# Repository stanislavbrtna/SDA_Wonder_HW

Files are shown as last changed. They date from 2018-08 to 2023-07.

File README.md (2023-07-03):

# SDA Mk. 2 Hardware Sources
In the Board directory are KiCad project files for the Boards used in the SDA and in the case Directory there are FreeCAD files for the SDA case. You can find more info about the SDA Project on its [project page](https://hackaday.io/project/35165-sda-the-best-new-pda) on hackaday.io.

## Known Bugs - Rev2b (current)

 1. SD card slot casing is not grounded on the pcb, sd card insertion detection doesn't work because of it. This can be fixed by scraping off the protective mask near the pin and bridging ground and shielding  with a bit of solder.
 2. Pads for battery connector are too small and can be ripped out of place when device falls form sufficient height. This is sort-of fixed with second revision of the case by giving the battery better support.
 3. The stacked PCBs are a point of failure, stress is built up in the connecting pins during soldering. This stress can break the contacts after few years of use, temperature changes, drops of the device. Luckily, re-soldering these pins is an easy job.

## Known Bugs - Rev1

 1. Vcc is used as Vref, if battery goes under 3.3V, then ADC measurements are wrong.
 2. There is no under-voltage protection at the moment.
 3. There is currently no guide for battery connector alignment, if battery connector is misaligned battery doesn't make good contact. 

## Case R2 notes
Second revision was printed and tested. It contains optional holes for a speaker and a microphone. The add-on module and cradle works well. 

## Case notes
 Only the 3D printable case for SDA was printed and tested, the FreeCAD file also contains drawings of a cradle and an add-on module, those are still work-in progress.

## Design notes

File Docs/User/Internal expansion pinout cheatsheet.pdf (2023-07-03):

+ AFs | MCU pin | Exc pin number | Connector number | Connector number | Exc pin number | MCU pin | + AFs
TIM4_CH4 | PD15 | 01 | 1 | 2 | 09 | PB15 | SPI2_MOSI
TIM4_CH3 | PD14 | 02 | 3 | 4 | 10 | PB14 | SPI2_MISO
TIM4_CH2, TIM12_CH2 | PD13 | 03 | 5 | 6 | 11 | PB13 | SPI2_SCK
TIM4_CH1 | PD12 | 04 | 7 | 8 | GND | - | -
- | PD11 | 05 | 9 | 10 | VCC 3.3V | - | -
- | PD10 | 06 | 11 | 12 | 14 | PE12 | -
USART3_RX | PD09 | 07 | 13 | 14 | 15 | PE13 | TIM1_CH3
USART3_TX | PD08 | 08 | 15 | 16 | 16 | PE14 | TIM1_CH4

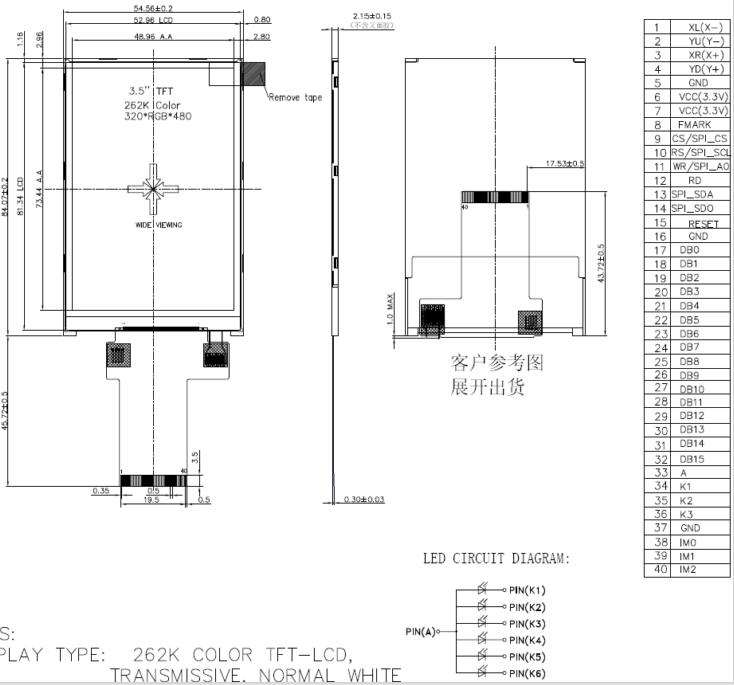
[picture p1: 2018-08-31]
Docs/Datasheets/LCD/lcd_pinout.jpg

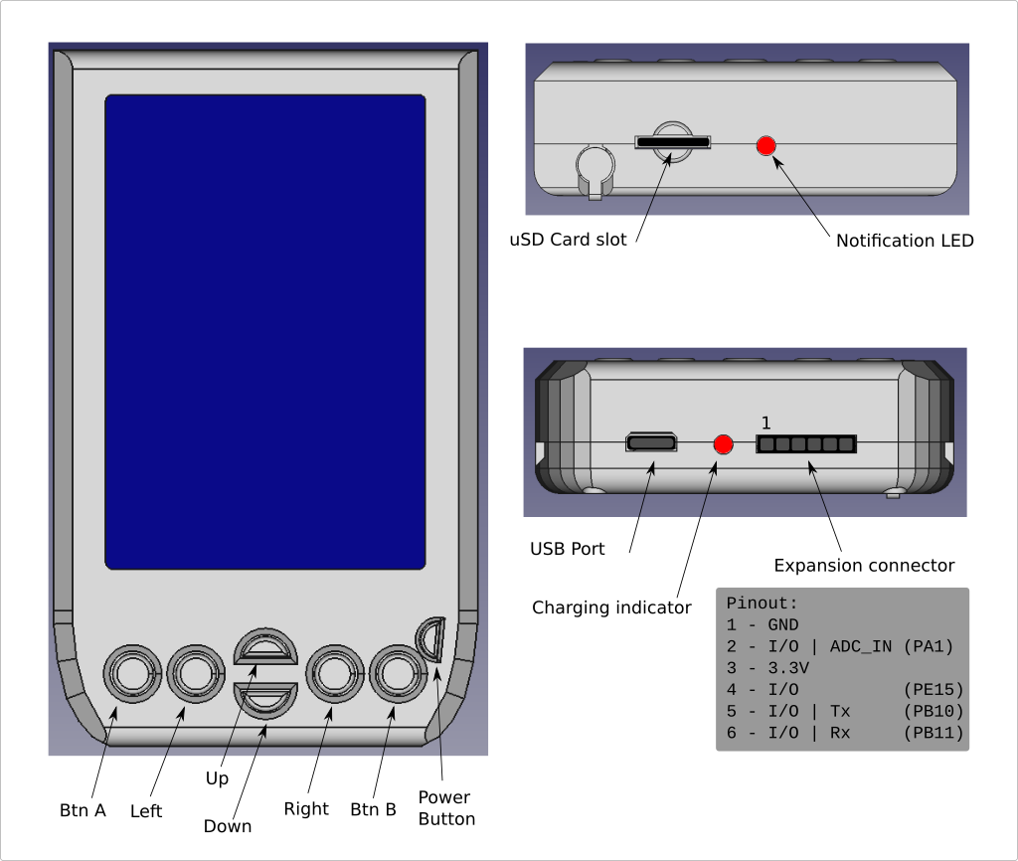
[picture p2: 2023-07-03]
Docs/User/diagram.png

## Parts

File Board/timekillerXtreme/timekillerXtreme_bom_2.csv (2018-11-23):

Component | Description | Part | References | Value | Footprint | Quantity Per PCB | Datasheet | TME_Part_number
1 | Unpolarized capacitor | C | C5 C7 C8 C13 C15 C16 C19 C20 C23 C28 C31 C32 | 100n | C_0805_HandSoldering | 12
2 | Unpolarized capacitor | C | C24 | 100u | C_1210_HandSoldering | 1
3 | Unpolarized capacitor | C | C14 C21 C22 C29 C33 | 2.2u | C_0805_HandSoldering | 5
4 | Unpolarized capacitor | C | C9 C10 | 3.3p | C_0805_HandSoldering | 2
5 | Unpolarized capacitor | C | C3 C4 C18 C30 | 4.7u | C_0805_HandSoldering | 4
6 | Unpolarized capacitor | C | C1 C2 | 47p | C_0805_HandSoldering | 2
7 | Unpolarized capacitor | C | C6 C17 | 47u | C_1210_HandSoldering | 2
8 | Unpolarized capacitor | C | C11 C12 | 8.2p | C_0805_HandSoldering | 2
9 | Diode | D | D2 | 1N4148 | D_MiniMELF | 1
10 | LED generic | LED | D1 | CHRG_LED | LED_D3.0mm_FlatTop | 1
11 | LED generic | LED | D4 | SYS_LED | LED_D3.0mm_FlatTop | 1
12 | Fuse, generic | Fuse | F1 | 1A | R_0805_HandSoldering | 1
13 | Generic connector, single row, 01x03 | Conn_01x03 | J1 | Battery | Conn_Nokia_BL-5C | 1
14 | point | TEST_1P | J7 | CAPTEST | Measurement_Point_Round-SMD-Pad_Small | 1
15 | Generic connector, single row, 01x03 | Conn_01x03 | J13 | CONN_01X03 | Pin_Header_Straight_1x03_Pitch1.27mm | 1
16 | Generic connector, single row, 01x02 | Conn_01x02 | J10 | Conn_01x02 | Pin_Header_Straight_1x02_Pitch2.00mm | 1
17 | Generic connector, single row, 01x06 | Conn_01x06 | J3 | Conn_Bottom_Expansion | Pin_Header__1x06_Pitch2.54mm-NoSilk | 1
18 | Generic connector, double row, 02x08, counter clockwise pin numbering scheme (similar to DIP packge numbering) | Conn_02x08_Counter_Clockwise | J4 | Conn_Internal_Expansion | Pin_Header_Straight_2x08_Pitch1.27mm | 1
19 | Generic connector, double row, 02x10, top/bottom pin numbering scheme (row 1: 1...pins_per_row, row2: pins_per_row+1 ... num_pins) | Conn_02x10_Top_Bottom | J5 | Conn_LCD_Board | Pin_Header_Straight_2x10_Pitch2.00mm | 1
20 | point | TEST_1P | J21 | PD0 | Measurement_Point_Round-SMD-Pad_Small | 1
21 | point | TEST_1P | J20 | PD1 | Measurement_Point_Round-SMD-Pad_Small | 1
22 | point | TEST_1P | J22 | PD3 | Measurement_Point_Round-SMD-Pad_Small | 1
23 | point | TEST_1P | J19 | PD4 | Measurement_Point_Round-SMD-Pad_Small | 1
24 | point | TEST_1P | J18 | PE10 | Measurement_Point_Round-SMD-Pad_Small | 1
25 | point | TEST_1P | J23 | PE11 | Measurement_Point_Round-SMD-Pad_Small | 1
26 | point | TEST_1P | J16 | PE8 | Measurement_Point_Round-SMD-Pad_Small | 1
27 | point | TEST_1P | J17 | PE9 | Measurement_Point_Round-SMD-Pad_Small | 1
28 | Generic connector, single row, 01x06 | Conn_01x06 | J12 | PROG | Pin_Header_Straight_1x06_Pitch1.27mm | 1
29 | point | TEST_1P | J24 | Pb12 | Measurement_Point_Round-SMD-Pad_Small | 1
30 | point | TEST_1P | J14 | TP_3.3V | Measurement_Point_Round-SMD-Pad_Small | 1
31 | point | TEST_1P | J9 | TP_AUDIO_L | Measurement_Point_Round-SMD-Pad_Small | 1
32 | point | TEST_1P | J8 | TP_AUDIO_R | Measurement_Point_Round-SMD-Pad_Small | 1
33 | point | TEST_1P | J25 | TP_BATT | Measurement_Point_Round-SMD-Pad_Small | 1
34 | point | TEST_1P | J11 | TP_USB | Measurement_Point_Round-SMD-Pad_Small | 1
35 | USB mini/micro connector | USB_OTG | J2 | USB_OTG | USB_Micro-B-CircularHoles | 1
36 |  | uSD-RESCUE-timekillerXtreme | J6 | uSD | ATTEND-SD-TME | 1 |  | ATTEND 112J-TDAR-R01
37 | Inductor | L | L1 | 4.7uH | L4x4mm | 1
38 | -60V Vds, -0.18A Id, P-Channel MOSFET, SOT-23-3 | NTR2101P | Q1 | IRLML6302 | SOT-23_Handsoldering | 1 | http://www.vishay.com/docs/70209/70209.pdf
39 | Transistor NPN (general) | Q_NPN_BCE | Q2 | PMBT3904.215 | SOT-23_Handsoldering | 1
40 | Resistor | R | R10 R11 R17 R18 | 0 | R_0603 | 4
41 | Resistor | R | R19 | 0 | R_0805_HandSoldering | 1
42 | Resistor | R | R1 R12 R13 R24 | 10k | R_0805_HandSoldering | 4
43 | Resistor | R | R9 | 150K | R_0805_HandSoldering | 1
44 | Resistor | R | R2 R14 R15 | 15k | R_0805_HandSoldering | 3
45 | Resistor | R | R16 | 220 | R_0805_HandSoldering | 1
46 | Resistor | R | R3 R4 | 27R | R_0805_HandSoldering | 2
47 | Resistor | R | R5 | 2k | R_0805_HandSoldering | 1
48 | Resistor | R | R6 | 470R | R_0805_HandSoldering | 1
49 | Resistor | R | R7 R20 R21 R22 R23 | 47k | R_0805_HandSoldering | 5
50 | Resistor | R | R8 | 680K | R_0805_HandSoldering | 1
51 | Single Pole Single Throw (SPST) switch | SW_SPST | SW2 | A | SW_PUSH_6mm_h5mm | 1
52 | Single Pole Single Throw (SPST) switch | SW_SPST | SW3 | B | SW_PUSH_6mm_h5mm | 1
53 | Single Pole Single Throw (SPST) switch | SW_SPST | SW6 | DOWN | SW_PUSH_6mm_h5mm | 1
54 | Single Pole Single Throw (SPST) switch | SW_SPST | SW4 | LEFT | SW_PUSH_6mm_h5mm | 1
55 | Single Pole Single Throw (SPST) switch | SW_SPST | SW1 | PWR | SW_PUSH_6mm_h5mm | 1
56 | Single Pole Single Throw (SPST) switch | SW_SPST | SW5 | RIGHT | SW_PUSH_6mm_h5mm | 1
57 | Single Pole Single Throw (SPST) switch | SW_SPST | SW8 | RST | SW_PUSH_6mm_h4.3mm | 1
58 | Single Pole Single Throw (SPST) switch | SW_SPST | SW7 | UP | SW_PUSH_6mm_h5mm | 1
59 | Cmos switch, SOT23-5 | AOZ1310 | U7 | AOZ1310 | SOT-23-5_HandSoldering | 1
60 |  | FT230XS-R | U2 | FT230XS-R | SSOP-16_5.3x6.2mm_Pitch0.65mm | 1
61 |  | MCP73831 | U1 | MCP73831 | SOT-23-5_HandSoldering | 1
62 |  | NCP1529 | U3 | NCP1529 | SOT-23-5_HandSoldering | 1
63 |  | STM32F407VGT6 | U5 | STM32F407VGT6 | LQFP-100_14x14mm_Pitch0.5mm | 1
64 |  | TLV431 | U4 | TLV431 | TSOT-23 | 1
65 |  | USBLC6 | U6 U8 U9 | USBLC6 | SOT-23-6_Handsoldering | 3
66 | point | TEST_1P | VREF1 | VREF | Measurement_Point_Round-SMD-Pad_Small | 1
67 | Two pin crystal | Crystal | Y2 | 16MHz | Crystal_SMD_HC49-HS-mini | 1
68 | Two pin crystal | Crystal | Y1 | 32.768 KHz | xtall_epso_mc146 | 1
Component Groups: | 68
Component Count: | 105
Fitted Components: | 105
Number of PCBs: | 1
Total components: | 105
Schematic Version: | 2
Schematic Date: | 2018-11-15
BoM Date: | P23.listopad2018,12:11:02CET
Schematic Source: | /home/stanislaw/SDA/2.0 Wonder/Board/timekillerXtreme/timekillerXtreme.sch
KiCad Version: | Eeschema 4.0.7-e2-6376~58~ubuntu16.04.1

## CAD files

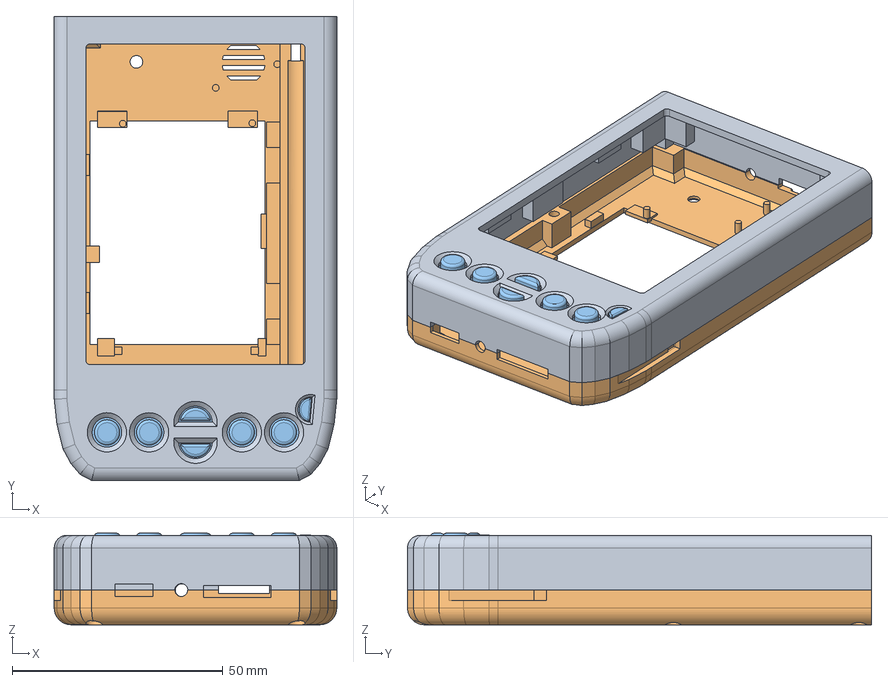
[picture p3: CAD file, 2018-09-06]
Case/wonder.fcstd
67.0 x 110.0 x 21.7 mm
Back
Buttons

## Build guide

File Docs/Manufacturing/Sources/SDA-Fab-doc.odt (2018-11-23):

Description | Part | References | Value | Quantity Per PCB
Unpolarized capacitor | C | C5 C7 C8 C13 C15 C16 C19 C20 C23 C28 C31 C32 | 100n | 12
Unpolarized capacitor | C | C24 | 100u | 1
Unpolarized capacitor | C | C14 C21 C22 C29 C33 | 2.2u | 5
Unpolarized capacitor | C | C9 C10 | 3.3p | 2
Unpolarized capacitor | C | C3 C4 C18 C30 | 4.7u | 4
Unpolarized capacitor | C | C1 C2 | 47p | 2
Unpolarized capacitor | C | C6 C17 | 47u | 2
Unpolarized capacitor | C | C11 C12 | 8.2p | 2
Diode | D | D2 | 1N4148 | 1
LED generic | LED | D1 | CHRG_LED | 1
LED generic | LED | D4 | SYS_LED | 1
Fuse, generic | Fuse | F1 | 1A | 1
Conn_Nokia_BL-5C | Conn_01x03 | J1 | Battery Connector | 1
Generic connector, 01x03 | Conn_01x03 | J13 | CONN_01X03 | 1
External expansion connector | Conn_01x06 | J3 | Conn_Bottom_Expansion | 1
Internal expansion connector | Conn_02x08 | J4 | Conn_Internal_Expansion | 1
Programming connector | Conn_01x06 | J12 | PROG | 1
SD card slot | uSD-timekillerXtreme | J6 | uSD | 1
Inductor | L | L1 | 4.7uH | 1
P-Channel MOSFET, SOT-23-3 | NTR2101P | Q1 | IRLML6302 | 1
Transistor NPN (general) | Q_NPN_BCE | Q2 | PMBT3904.215 | 1
Resistor | R | R19 | 0 | 1
Resistor | R | R1 R12 R13 R24 | 10k | 4
Resistor | R | R9 | 150k | 1
Resistor | R | R2 R14 R15 | 15k | 3
Resistor | R | R16 | 220 | 1
Resistor | R | R3 R4 | 27R | 2
Resistor | R | R5 | 2k | 1
Resistor | R | R6 | 470R | 1
Resistor | R | R7 R20 R21 R22 R23 | 47k | 5
Resistor | R | R8 | 680k | 1
Single Pole Single Throw (SPST) switch | SW_SPST | SW8 | RST | 1
Single Pole Single Throw (SPST) switch | SW_SPST | SW1 - SW7 | A, B, L, R, U, D, PWR | 7
Cmos switch, SOT23-5 | AOZ1310 | U7 | AOZ1310 | 1
FTDI usb to seriál | FT230XS-R | U2 | FT230XS-R | 1
Battery management | MCP73831 | U1 | MCP73831 | 1
Voltage reg. | NCP1529 | U3 | NCP1529 | 1
MCU | STM32F407VGT6 | U5 | STM32F407VGT6 | 1
Voltage refrerence | TLV431 | U4 | TLV431 | 1
ESD protection | USBLC6 | U6 U8 U9 | USBLC6 | 3
Two pin crystal | Crystal | Y2 | 16MHz | 1

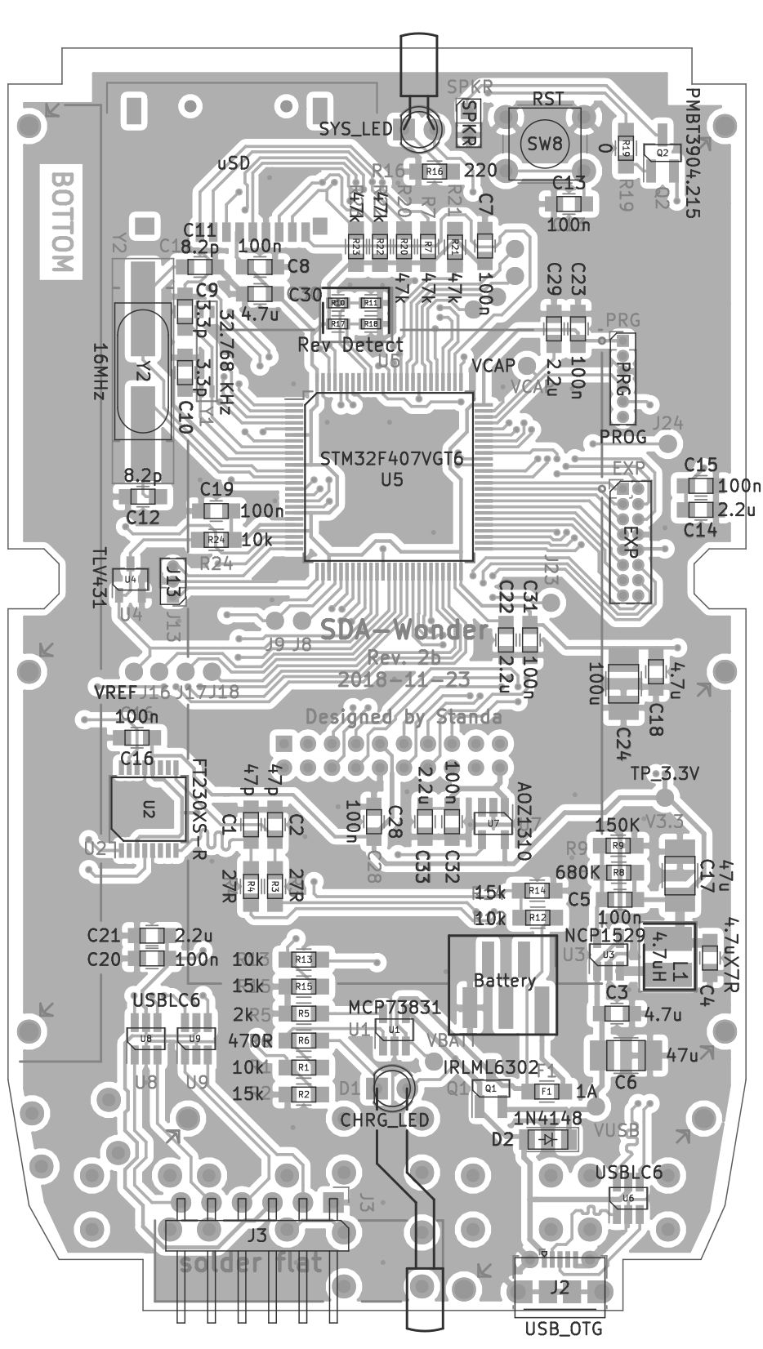
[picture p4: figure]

Two pin crystal SDA-Wonder Rev2b Assembly docs, Standa 2018 hackaday.io/project/35165-sda-the-best-new-pda github.com/stanislavbrtna/SDA_Wonder_HW | Crystal | Y1 | 32.768 KHz | 1

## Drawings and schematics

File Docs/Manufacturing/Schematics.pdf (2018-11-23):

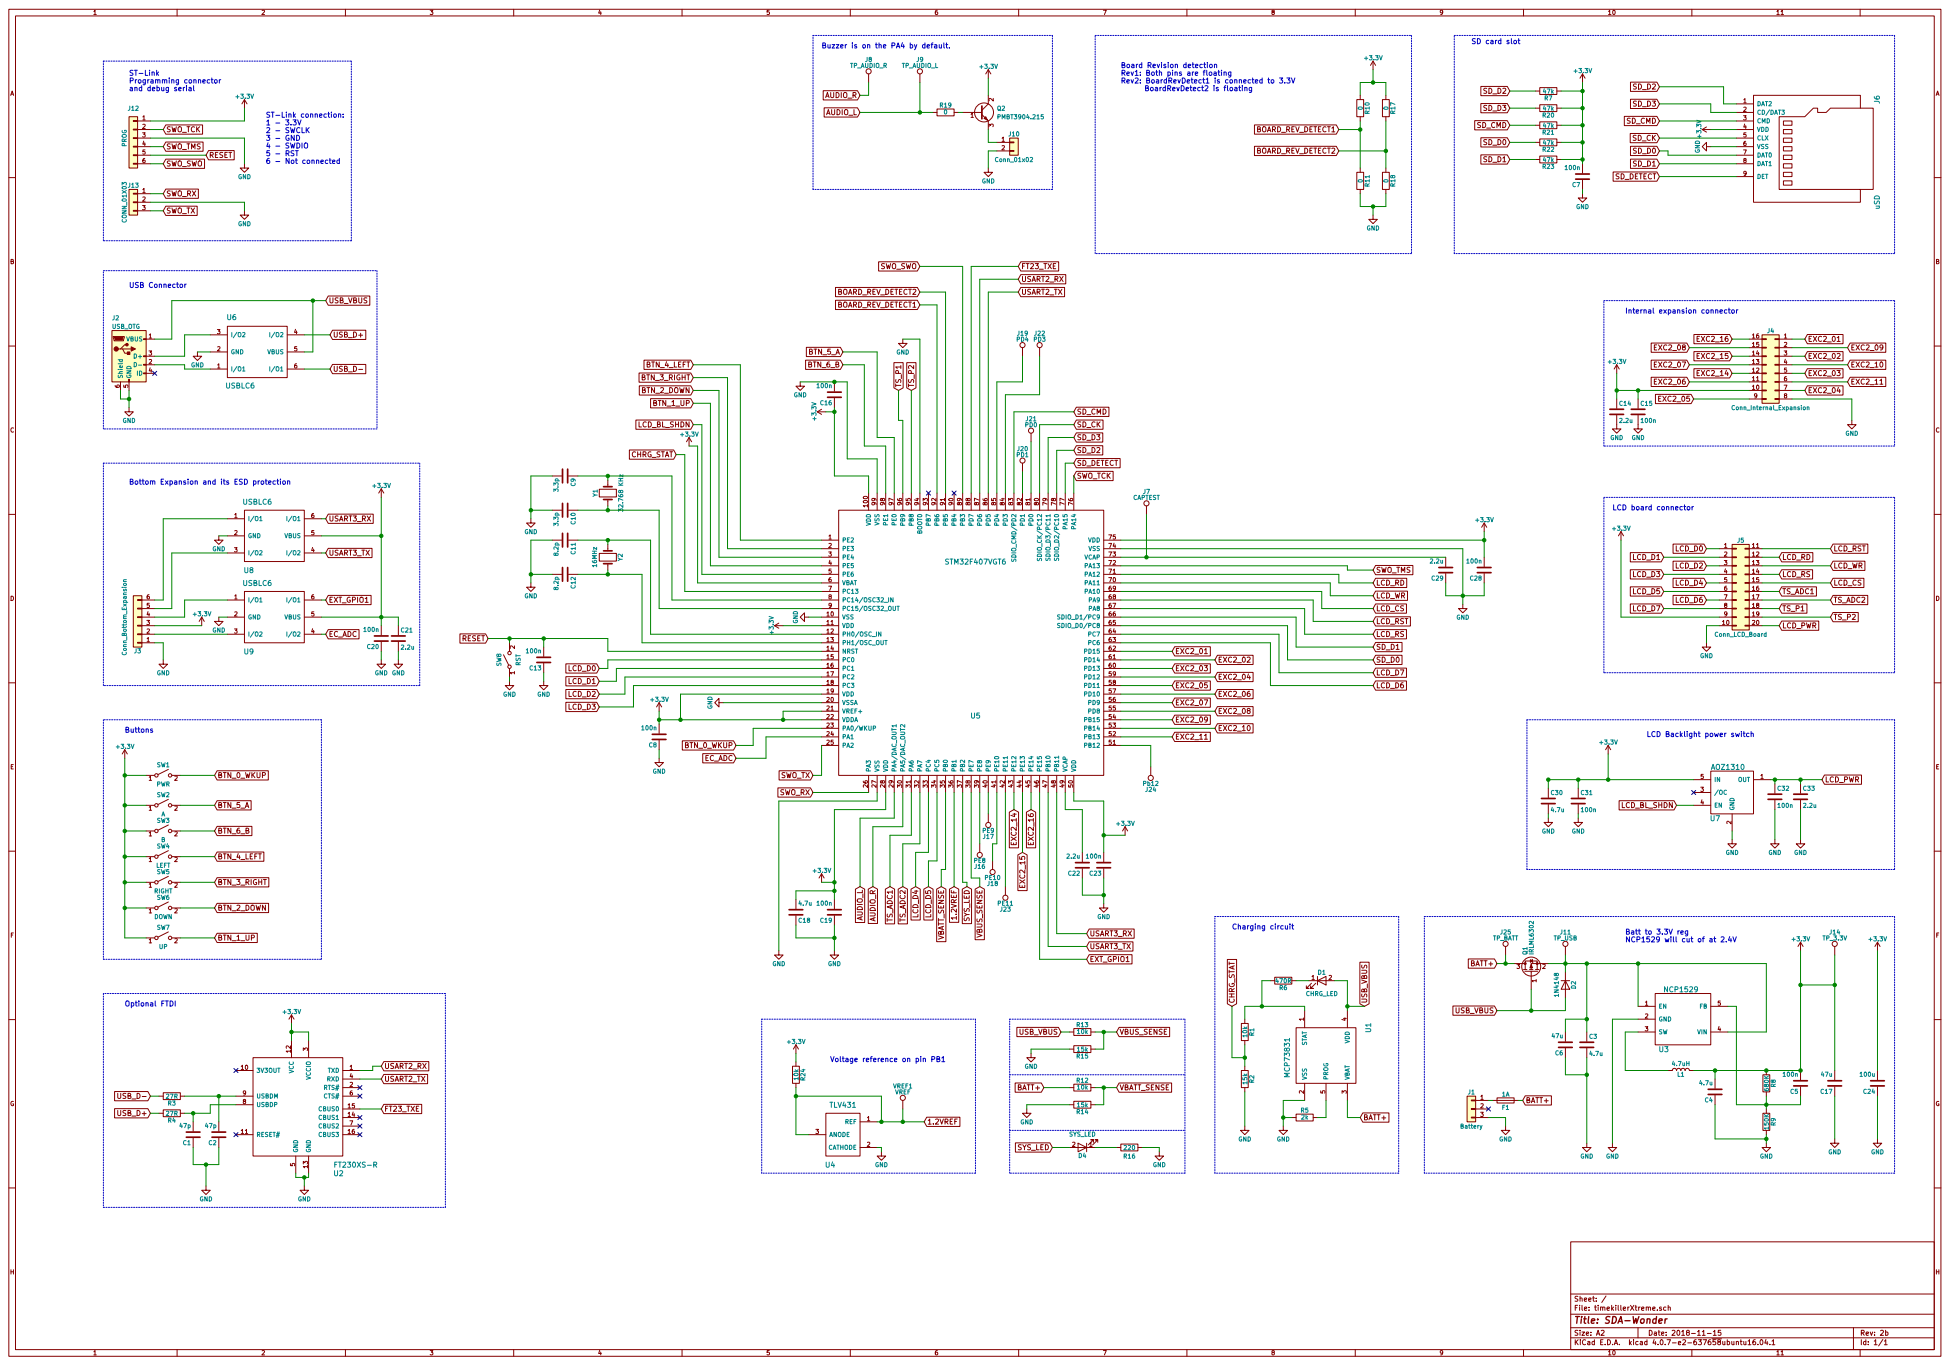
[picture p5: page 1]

Description | Part | References | Value | Quantity Per PCB
Unpolarized capacitor | C | C5 C7 C8 C13 C15 C16 C19 C20 C23 C28 C31 C32 | 100n | 12
Unpolarized capacitor | C | C24 | 100u | 1
Unpolarized capacitor | C | C14 C21 C22 C29 C33 | 2.2u | 5
Unpolarized capacitor | C | C9 C10 | 3.3p | 2
Unpolarized capacitor | C | C3 C4 C18 C30 | 4.7u | 4
Unpolarized capacitor | C | C1 C2 | 47p | 2
Unpolarized capacitor | C | C6 C17 | 47u | 2
Unpolarized capacitor | C | C11 C12 | 8.2p | 2
Diode | D | D2 | 1N4148 | 1
LED generic | LED | D1 | CHRG_LED | 1
LED generic | LED | D4 | SYS_LED | 1
Fuse, generic | Fuse | F1 | 1A | 1
Conn_Nokia_BL-5C | Conn_01x03 | J1 | Battery Connector | 1
Generic connector, 01x03 | Conn_01x03 | J13 | CONN_01X03 | 1
External expansion connector | Conn_01x06 | J3 | Conn_Bottom_Expansion | 1
Internal expansion connector | Conn_02x08 | J4 | Conn_Internal_Expansion | 1
Programming connector | Conn_01x06 | J12 | PROG | 1
SD card slot | uSD-timekillerXtreme | J6 | uSD | 1
Inductor | L | L1 | 4.7uH | 1
P-Channel MOSFET, SOT-23-3 | NTR2101P | Q1 | IRLML6302 | 1
Transistor NPN (general) | Q_NPN_BCE | Q2 | PMBT3904.215 | 1
Resistor | R | R19 | 0 | 1
Resistor | R | R1 R12 R13 R24 | 10k | 4
Resistor | R | R9 | 150k | 1
Resistor | R | R2 R14 R15 | 15k | 3
Resistor | R | R16 | 220 | 1
Resistor | R | R3 R4 | 27R | 2
Resistor | R | R5 | 2k | 1
Resistor | R | R6 | 470R | 1
Resistor | R | R7 R20 R21 R22 R23 | 47k | 5
Resistor | R | R8 | 680k | 1
Single Pole Single Throw (SPST) switch | SW_SPST | SW8 | RST | 1
Single Pole Single Throw (SPST) switch | SW_SPST | SW1 - SW7 | A, B, L, R, U, D, PWR | 7
Cmos switch, SOT23-5 | AOZ1310 | U7 | AOZ1310 | 1
FTDI usb to seriál | FT230XS-R | U2 | FT230XS-R | 1
Battery management | MCP73831 | U1 | MCP73831 | 1
Voltage reg. | NCP1529 | U3 | NCP1529 | 1
MCU | STM32F407VGT6 | U5 | STM32F407VGT6 | 1
Voltage refrerence | TLV431 | U4 | TLV431 | 1
ESD protection | USBLC6 | U6 U8 U9 | USBLC6 | 3
Two pin crystal | Crystal | Y2 | 16MHz | 1
Two pin crystal | Crystal | Y1 | 32.768 KHz | 1

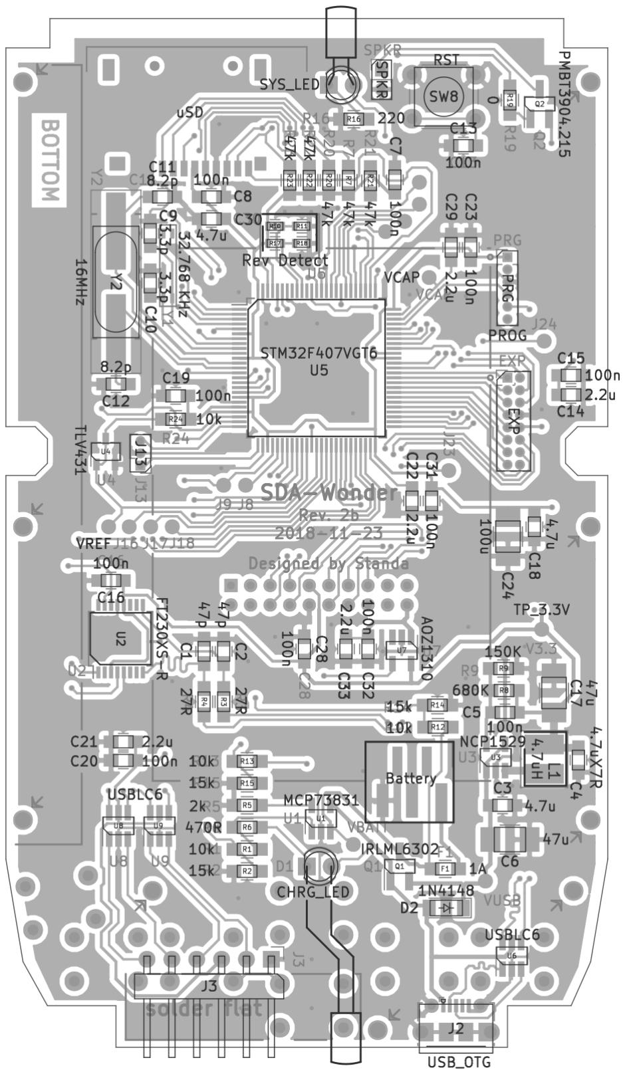
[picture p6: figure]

## SDA-Wonder Rev2b Assembly docs, Standa 2018

### hackaday.io/project/35165-sda-the-best-new-pda github.com/stanislavbrtna/SDA_Wonder_HW

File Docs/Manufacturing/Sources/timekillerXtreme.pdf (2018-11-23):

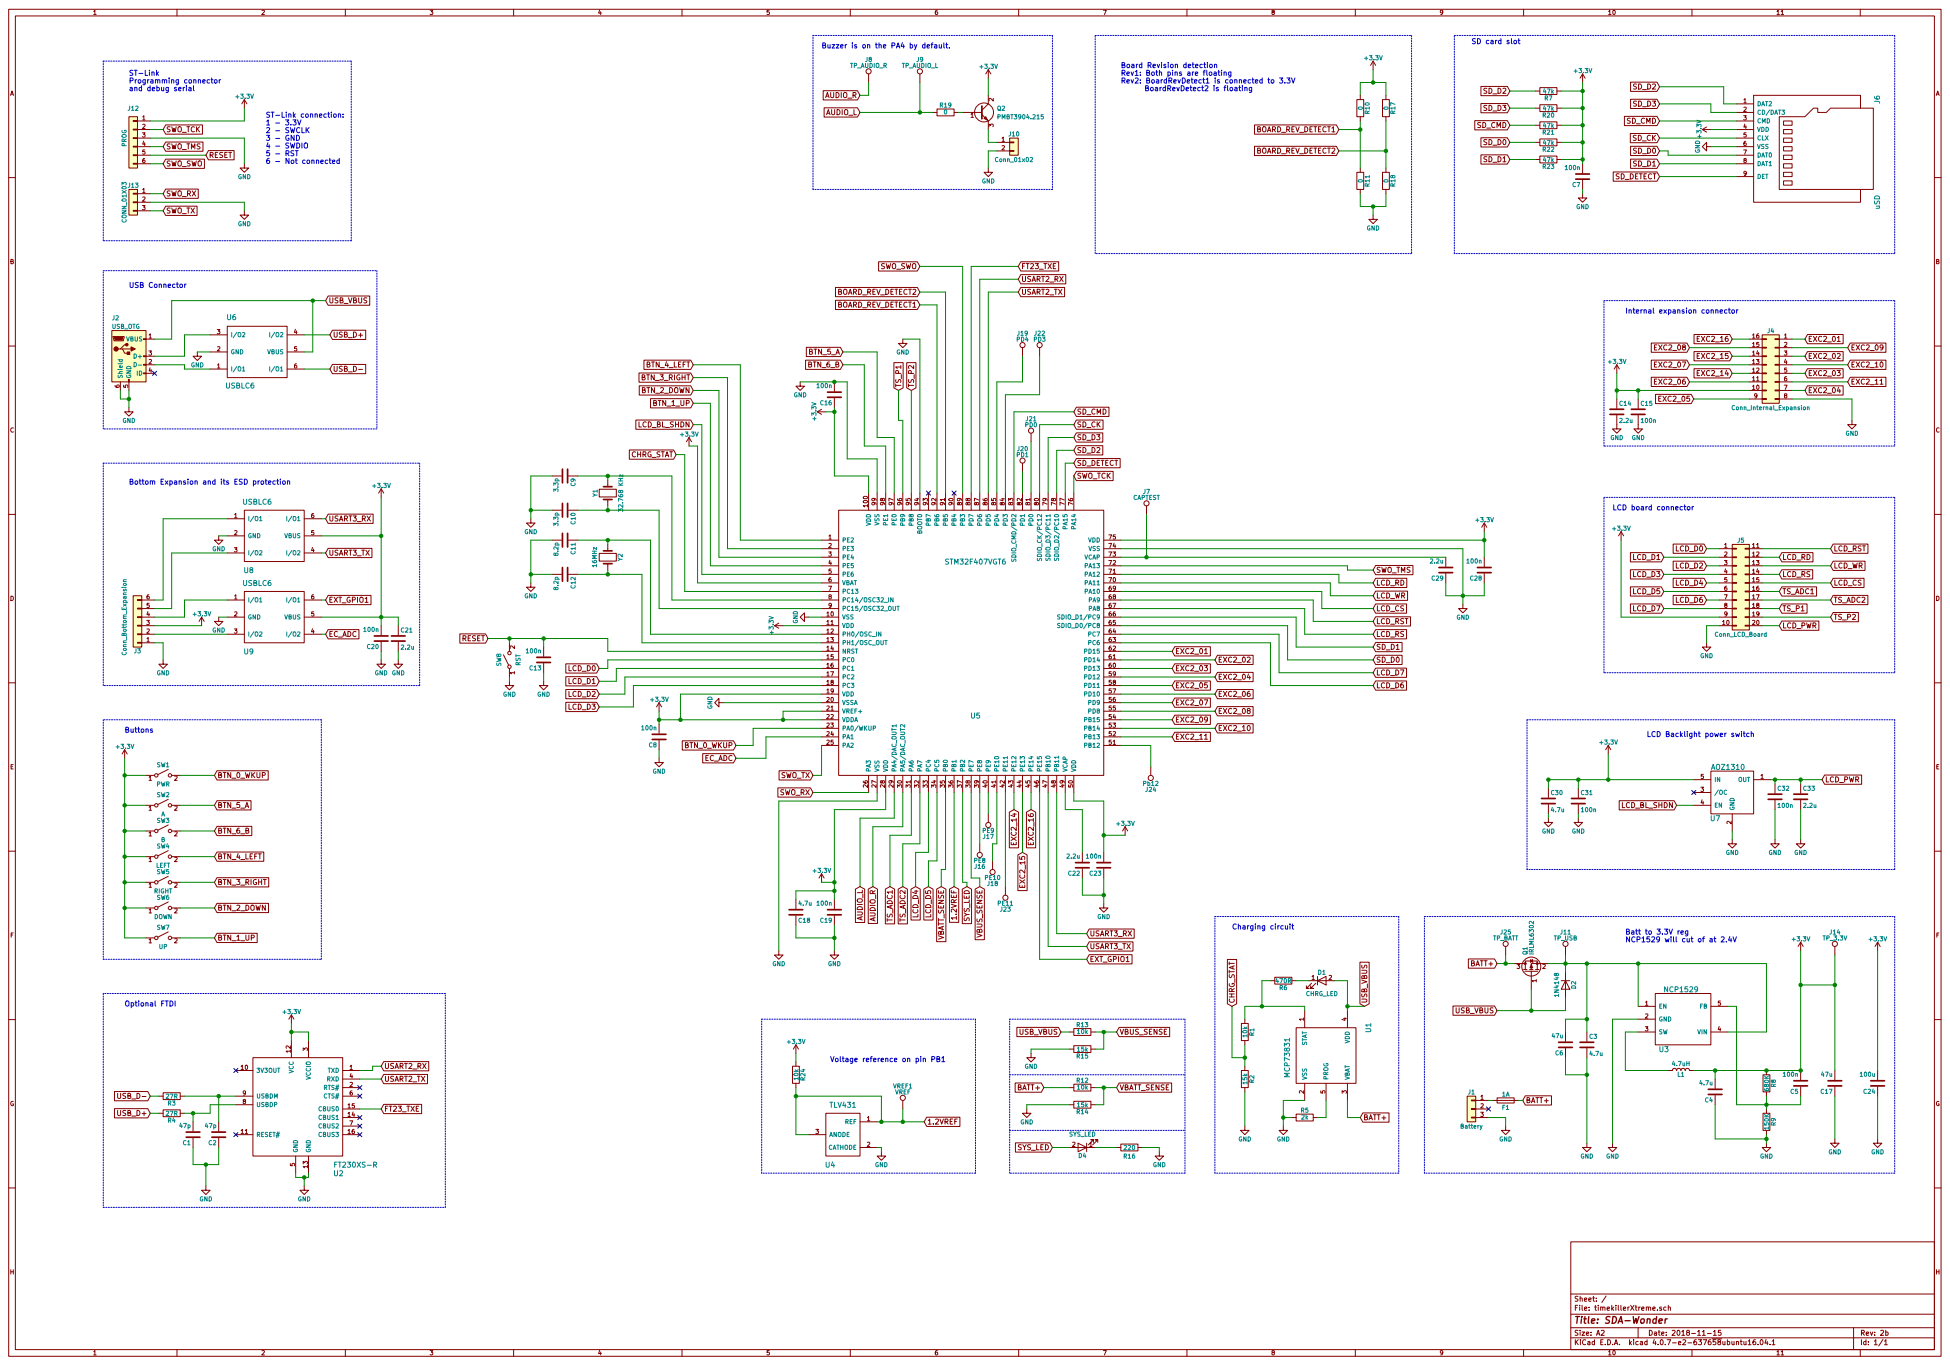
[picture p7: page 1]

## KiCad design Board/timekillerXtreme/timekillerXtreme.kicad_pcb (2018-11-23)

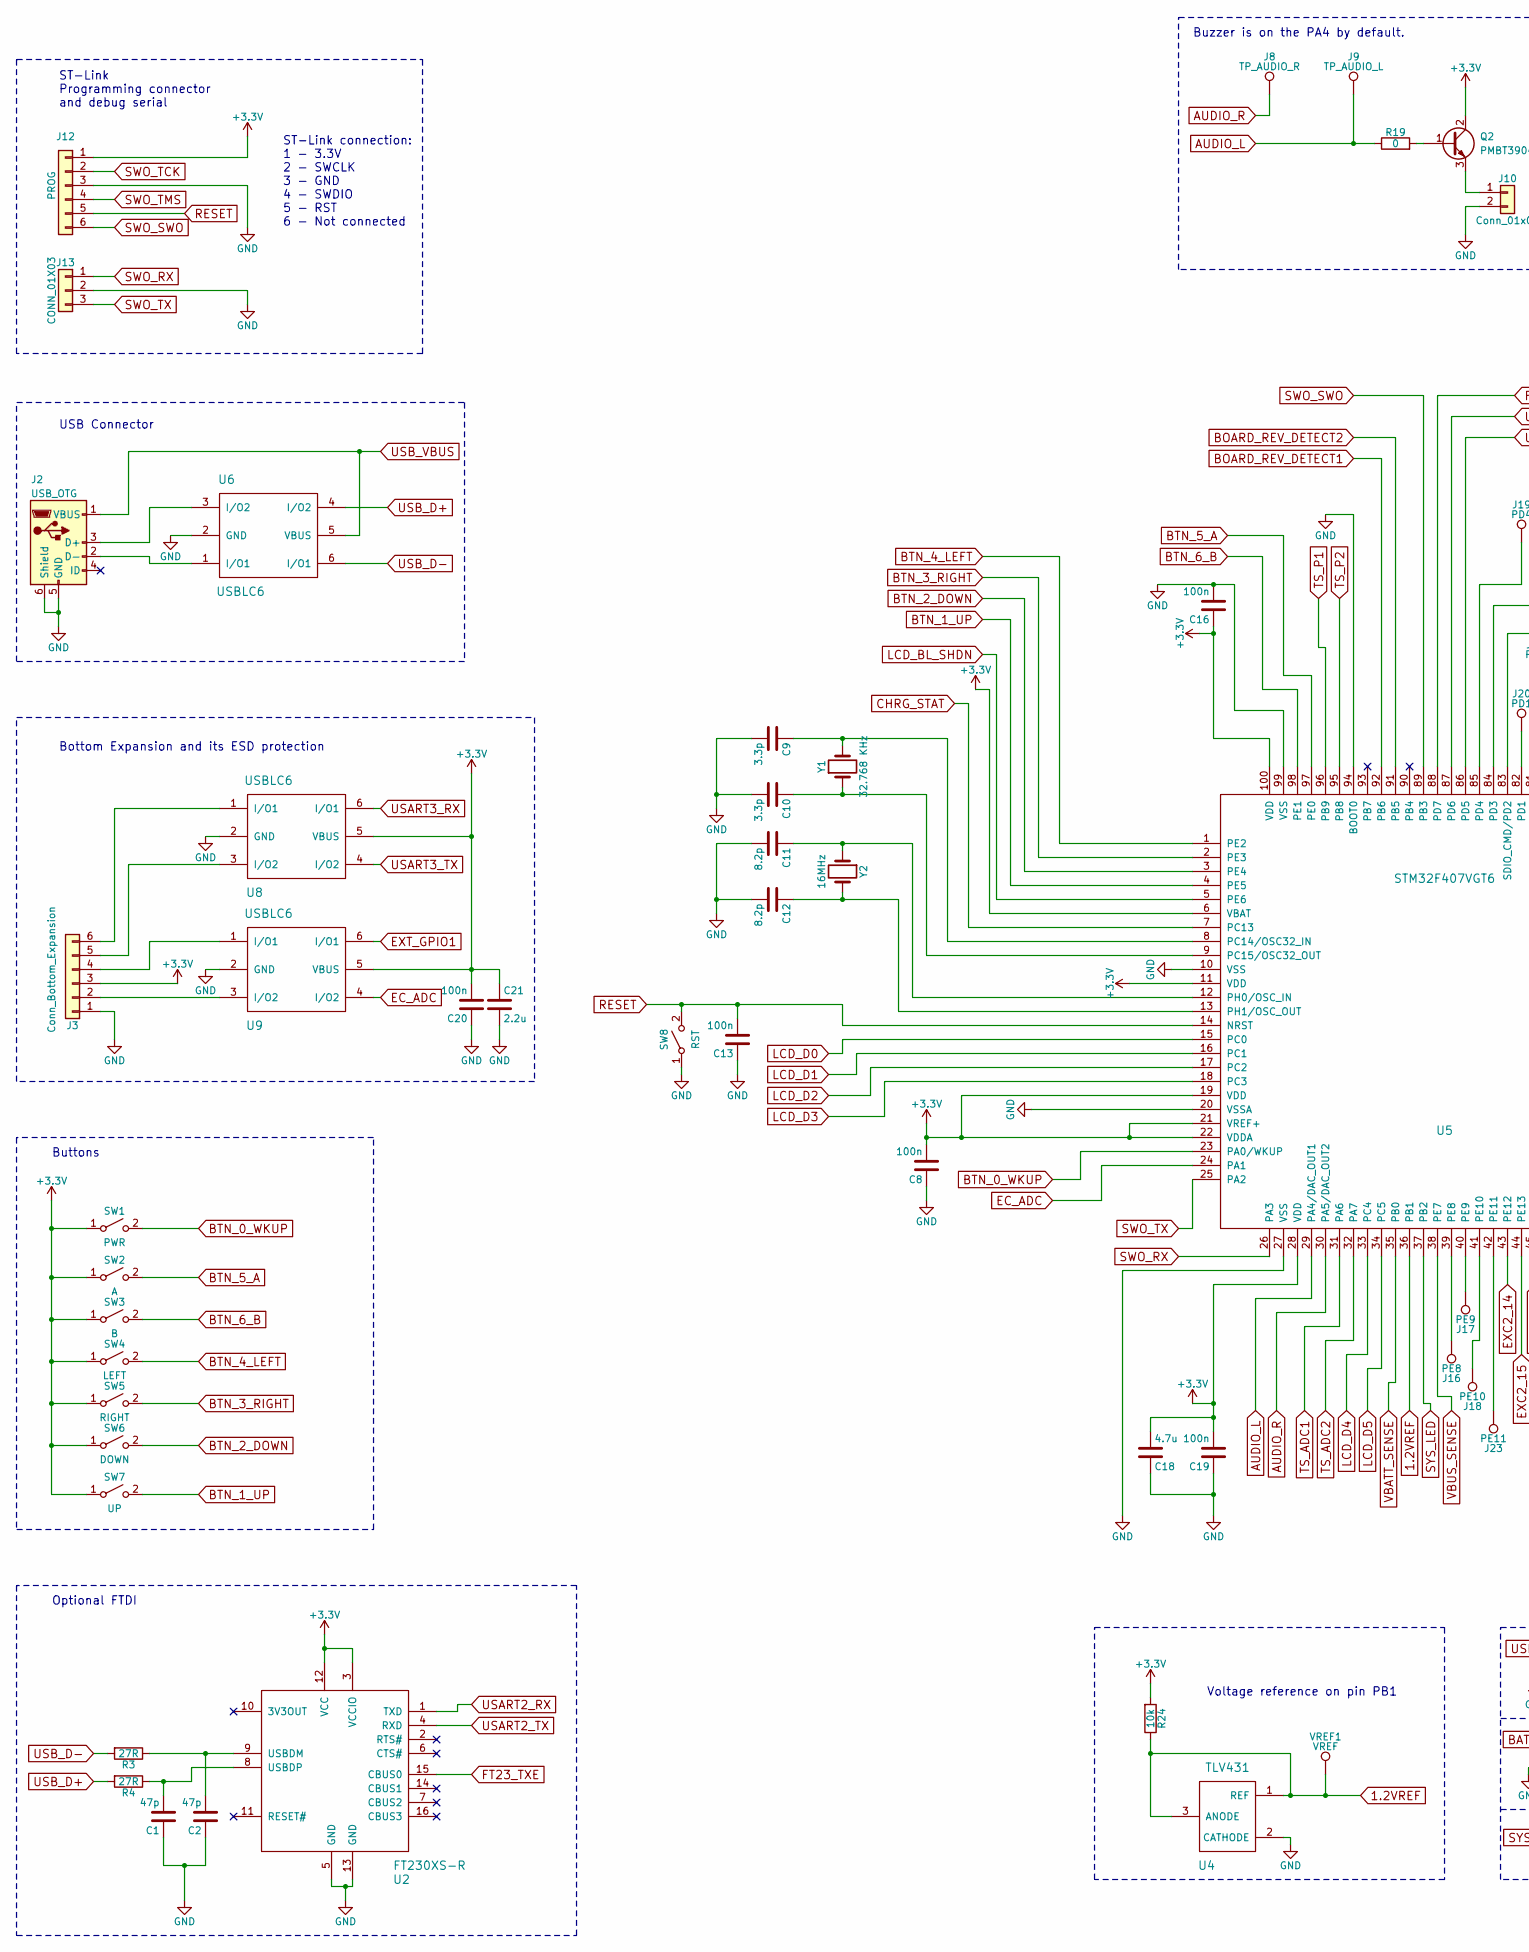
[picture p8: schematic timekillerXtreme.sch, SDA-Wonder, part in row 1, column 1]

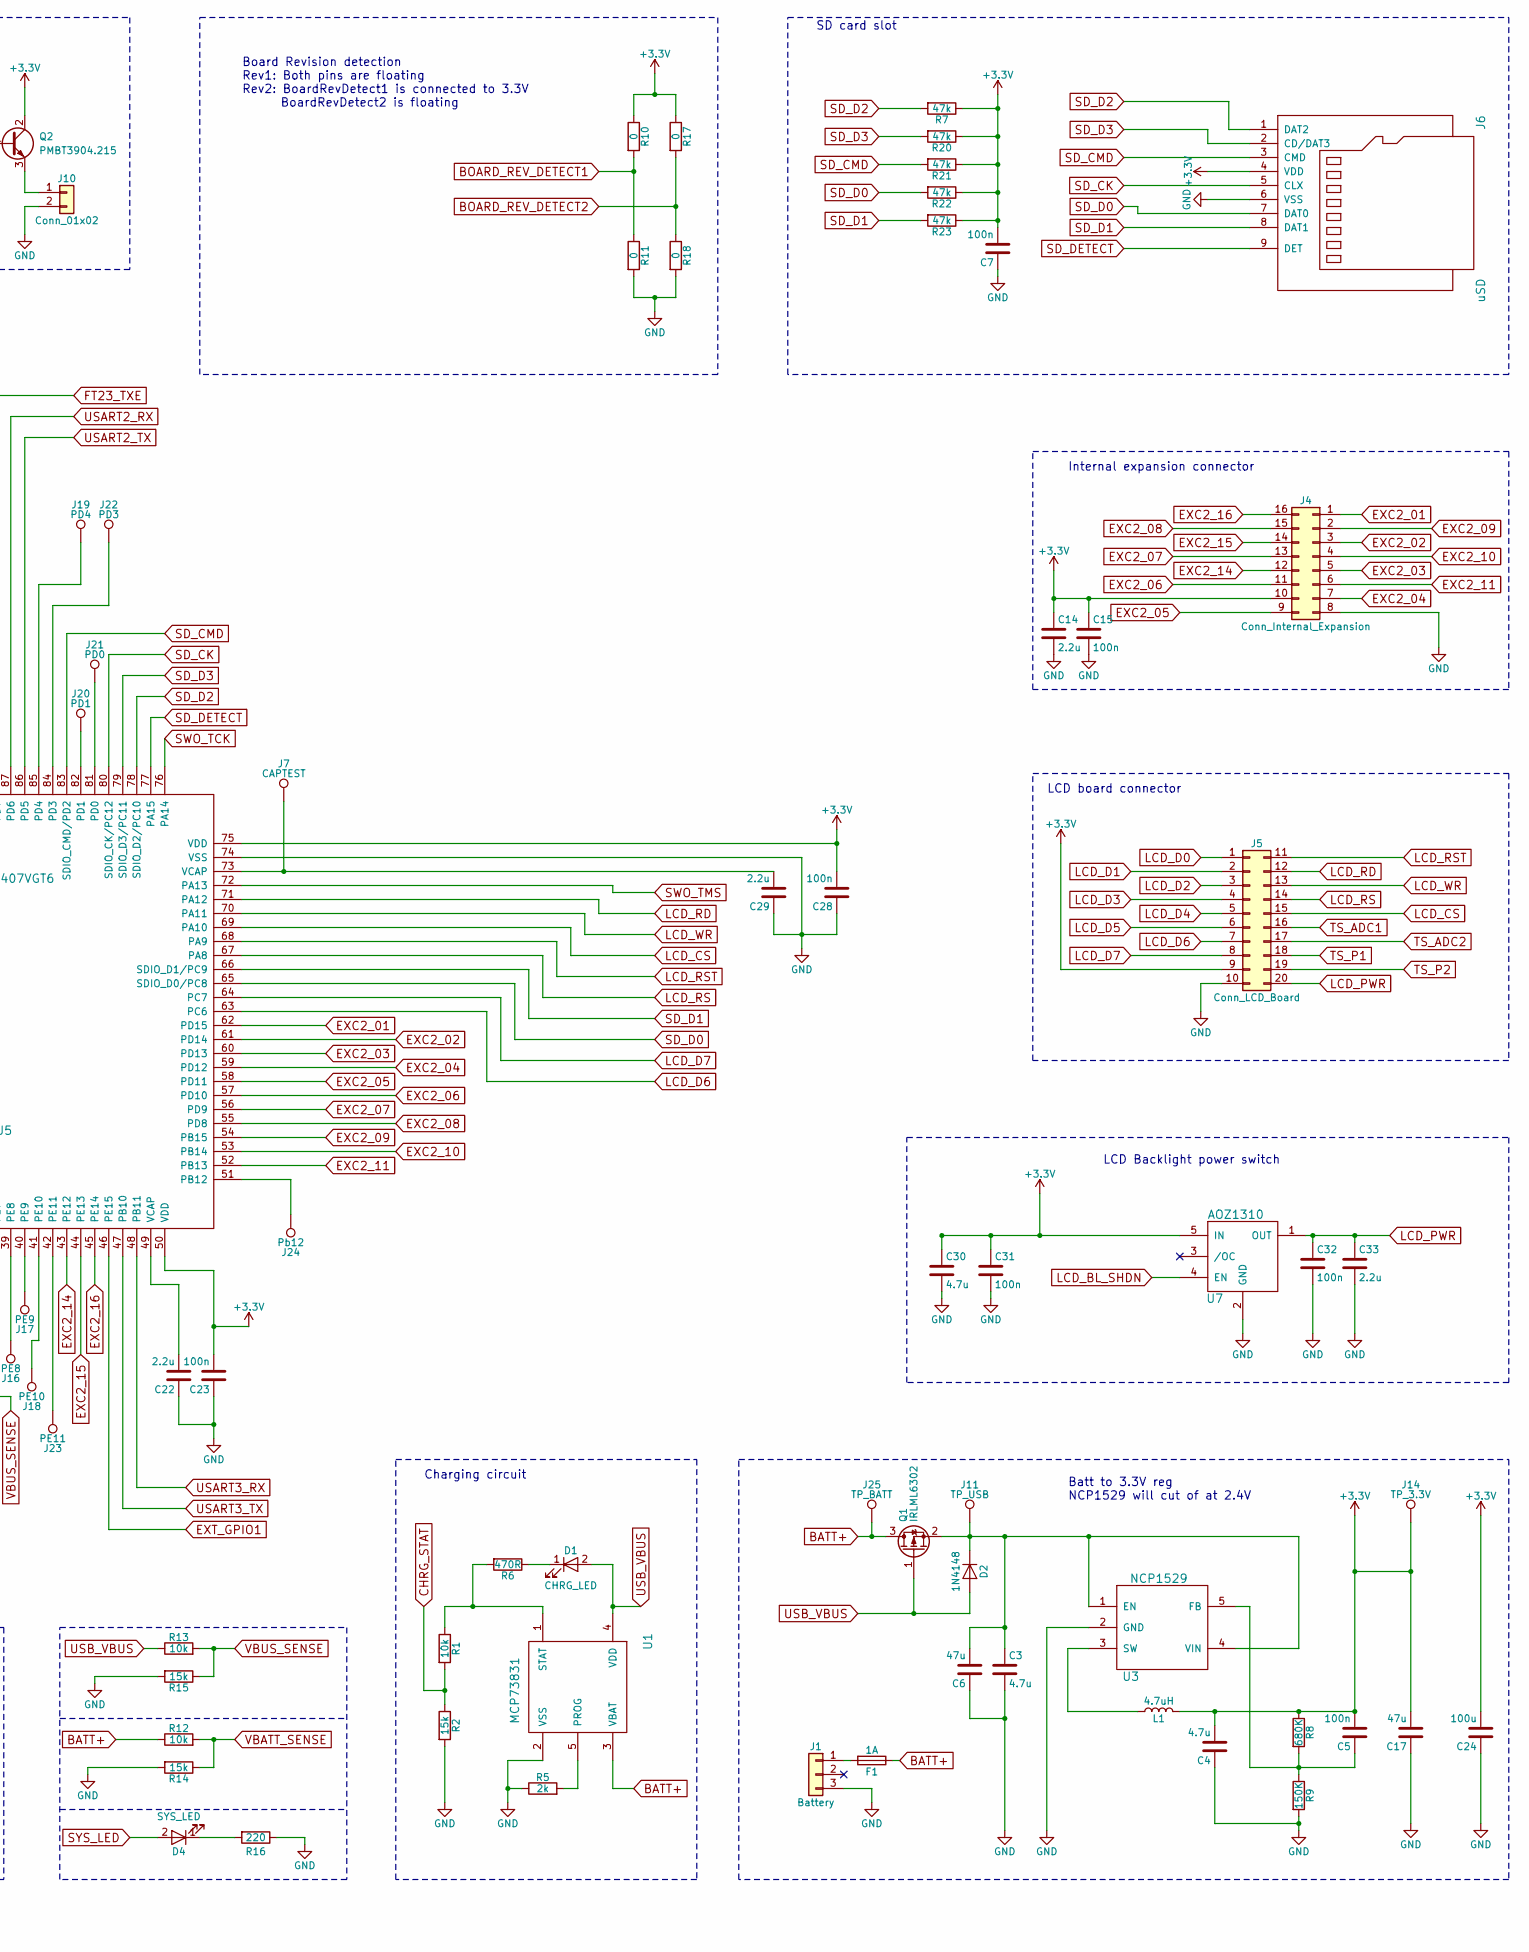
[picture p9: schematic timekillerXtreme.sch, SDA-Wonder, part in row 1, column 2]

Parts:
C1, C2: 47p; C_0805_HandSoldering
C3, C4, C18, C30: 4.7u; C_0805_HandSoldering
C5, C7, C8, C13, C15, C16, C19, C20, C23, C28, C31, C32: 100n; C_0805_HandSoldering
C6, C17: 47u; C_1210_HandSoldering
C9, C10: 3.3p; C_0805_HandSoldering
C11, C12: 8.2p; C_0805_HandSoldering
C14, C21, C22, C29, C33: 2.2u; C_0805_HandSoldering
C24: 100u; C_1210_HandSoldering
D1: CHRG_LED; LED_D3.0mm_FlatTop
D2: 1N4148; D_MiniMELF
D4: SYS_LED; LED_D3.0mm_FlatTop
F1: 1A; R_0805_HandSoldering
J1: Battery; Conn_Nokia_BL-5C
J2: USB_OTG; USB_Micro-B-CircularHoles
J3: Conn_Bottom_Expansion; Pin_Header__1x06_Pitch2.54mm-NoSilk
J4: Conn_Internal_Expansion; Pin_Header_Straight_2x08_Pitch1.27mm
J5: Conn_LCD_Board; Pin_Header_Straight_2x10_Pitch2.00mm
J6: uSD; ATTEND-SD-TME
J7: CAPTEST; Measurement_Point_Round-SMD-Pad_Small
J8: TP_AUDIO_R; Measurement_Point_Round-SMD-Pad_Small
J9: TP_AUDIO_L; Measurement_Point_Round-SMD-Pad_Small
J10: Conn_01x02; Pin_Header_Straight_1x02_Pitch2.00mm
J11: TP_USB; Measurement_Point_Round-SMD-Pad_Small
J12: PROG; Pin_Header_Straight_1x06_Pitch1.27mm
J13: CONN_01X03; Pin_Header_Straight_1x03_Pitch1.27mm
J14: TP_3.3V; Measurement_Point_Round-SMD-Pad_Small
J16: PE8; Measurement_Point_Round-SMD-Pad_Small
J17: PE9; Measurement_Point_Round-SMD-Pad_Small
J18: PE10; Measurement_Point_Round-SMD-Pad_Small
J19: PD4; Measurement_Point_Round-SMD-Pad_Small
J20: PD1; Measurement_Point_Round-SMD-Pad_Small
J21: PD0; Measurement_Point_Round-SMD-Pad_Small
J22: PD3; Measurement_Point_Round-SMD-Pad_Small
J23: PE11; Measurement_Point_Round-SMD-Pad_Small
J24: Pb12; Measurement_Point_Round-SMD-Pad_Small
J25: TP_BATT; Measurement_Point_Round-SMD-Pad_Small
L1: 4.7uH; L4x4mm
Q1: IRLML6302; SOT-23_Handsoldering
Q2: PMBT3904.215; SOT-23_Handsoldering
R1, R12, R13, R24: 10k; R_0805_HandSoldering
R2, R14, R15: 15k; R_0805_HandSoldering
R3, R4: 27R; R_0805_HandSoldering
R5: 2k; R_0805_HandSoldering
R6: 470R; R_0805_HandSoldering
R7, R20, R21, R22, R23: 47k; R_0805_HandSoldering
R8: 680K; R_0805_HandSoldering
R9: 150K; R_0805_HandSoldering
R10, R11, R17, R18: 0; R_0603
R16: 220; R_0805_HandSoldering
R19: 0; R_0805_HandSoldering
SW1: PWR; SW_PUSH_6mm_h5mm
SW2: A; SW_PUSH_6mm_h5mm
SW3: B; SW_PUSH_6mm_h5mm
SW4: LEFT; SW_PUSH_6mm_h5mm
SW5: RIGHT; SW_PUSH_6mm_h5mm
SW6: DOWN; SW_PUSH_6mm_h5mm
SW7: UP; SW_PUSH_6mm_h5mm
SW8: RST; SW_PUSH_6mm_h4.3mm
U1: MCP73831; SOT-23-5_HandSoldering
U2: FT230XS-R; SSOP-16_5.3x6.2mm_Pitch0.65mm
U3: NCP1529; SOT-23-5_HandSoldering
U4: TLV431; TSOT-23
U5: STM32F407VGT6; LQFP-100_14x14mm_Pitch0.5mm
U6, U8, U9: USBLC6; SOT-23-6_Handsoldering
U7: AOZ1310; SOT-23-5_HandSoldering
VREF1: VREF; Measurement_Point_Round-SMD-Pad_Small
Y1: 32.768 KHz; xtall_epso_mc146
Y2: 16MHz; Crystal_SMD_HC49-HS-mini

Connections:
AUDIO_L: J9.1, R19.1, U5.29 (PA4/DAC_OUT1)
AUDIO_R: J8.1, U5.30 (PA5/DAC_OUT2)
BATT+: F1.1, J25.1, Q1.3 (D), R12.1, U1.3 (VBAT); also elsewhere on the board
BOARD_REV_DETECT1: R10.2, R11.1, U5.92 (PB6)
BOARD_REV_DETECT2: R17.2, R18.1, U5.91 (PB5)
BTN_0_WKUP: SW1.2 (B), U5.23 (PA0/WKUP)
BTN_1_UP: SW7.2 (B), U5.4 (PE5)
BTN_2_DOWN: SW6.2 (B), U5.3 (PE4)
BTN_3_RIGHT: SW5.2 (B), U5.2 (PE3)
BTN_4_LEFT: SW4.2 (B), U5.1 (PE2)
BTN_5_A: SW2.2 (B), U5.97 (PE0)
BTN_6_B: SW3.2 (B), U5.98 (PE1)
CHRG_STAT: R1.2, R2.1, U5.7 (PC13)
EC_ADC: U5.24 (PA1), U9.4 (I/O2)
EXC2_01: J4.1, U5.62 (PD15); also elsewhere on the board
EXC2_02: J4.3, U5.61 (PD14); also elsewhere on the board
EXC2_03: J4.5, U5.60 (PD13); also elsewhere on the board
EXC2_04: J4.7, U5.59 (PD12); also elsewhere on the board
EXC2_05: J4.9, U5.58 (PD11); also elsewhere on the board
EXC2_06: J4.11, U5.57 (PD10); also elsewhere on the board
EXC2_07: J4.13, U5.56 (PD9); also elsewhere on the board
EXC2_08: J4.15, U5.55 (PD8); also elsewhere on the board
EXC2_09: J4.2, U5.54 (PB15); also elsewhere on the board
EXC2_10: J4.4, U5.53 (PB14); also elsewhere on the board
EXC2_11: J4.6, U5.52 (PB13); also elsewhere on the board
EXC2_14: J4.12, U5.43 (PE12); also elsewhere on the board
EXC2_15: J4.14, U5.44 (PE13); also elsewhere on the board
EXC2_16: J4.16, U5.45 (PE14); also elsewhere on the board
EXT_GPIO1: U5.46 (PE15), U9.6 (I/O1)
FT23_TXE: U2.15 (CBUS0), U5.88 (PD7)
GND: C1.1, C2.1, C3.2, C4.1, C6.1, C7.1, C8.1, C9.2, C10.2, C11.2, C12.2, C13.1, C14.2, C15.2, C16.2, C17.1, C18.1, C19.1, C20.1, C21.2, C22.1, C23.1, C24.1, C28.1, C29.1, C30.2, C31.2, C32.2, C33.2, J1.3, J2.5 (GND), J2.6 (Shield), J3.1, J4.8, J5.10, J6.6 (VSS), J10.2, J12.3, J13.2, R2.2, R5.1, R9.2, R11.2, R14.2, R15.2, R16.1, R18.2, SW8.1 (A), U1.2 (VSS), U2.5 (GND), U2.13 (GND), U3.2 (GND), U4.2 (CATHODE), U5.10 (VSS), U5.20 (VSSA), U5.27 (VSS), U5.74 (VSS), U5.94 (BOOT0), U5.99 (VSS), U6.2 (GND), U7.2 (GND), U8.2 (GND), U9.2 (GND); also elsewhere on the board
LCD_BL_SHDN: U5.5 (PE6), U7.4 (EN)
LCD_CS: J5.15, U5.69 (PA10)
LCD_D0: J5.1, U5.15 (PC0)
LCD_D1: J5.2, U5.16 (PC1)
LCD_D2: J5.3, U5.17 (PC2)
LCD_D3: J5.4, U5.18 (PC3)
LCD_D4: J5.5, U5.33 (PC4)
LCD_D5: J5.6, U5.34 (PC5)
LCD_D6: J5.7, U5.63 (PC6)
LCD_D7: J5.8, U5.64 (PC7)
LCD_PWR: C32.1, C33.1, J5.20, U7.1 (OUT)
LCD_RD: J5.12, U5.71 (PA12)
LCD_RS: J5.14, U5.67 (PA8)
LCD_RST: J5.11, U5.68 (PA9)
LCD_WR: J5.13, U5.70 (PA11)
unnamed: C1.2, R4.1, U2.8 (USBDP)
unnamed: C2.2, R3.1, U2.9 (USBDM)
unnamed 48: C3.1, C6.2, D2.1 (K), J11.1, Q1.2 (S), U3.1 (EN), U3.4 (VIN); also elsewhere on the board
unnamed: C5.1, R8.2, R9.1, U3.5 (FB)
unnamed: C9.1, U5.8 (PC14/OSC32_IN), Y1.2
unnamed: C10.1, U5.9 (PC15/OSC32_OUT), Y1.1
unnamed: C11.1, U5.12 (PH0/OSC_IN), Y2.1
unnamed: C12.1, U5.13 (PH1/OSC_OUT), Y2.2
unnamed: C22.2, U5.49 (VCAP)
unnamed 55: C29.2, J7.1, U5.73 (VCAP); also elsewhere on the board
unnamed: D1.1 (K), R6.1
unnamed: D4.1 (K), R16.2
unnamed: F1.2, J1.1
unnamed: J2.2 (D-), U6.1 (I/O1)
unnamed: J2.3 (D+), U6.3 (I/O2)
unnamed: J3.2, U9.3 (I/O2)
unnamed: J3.4, U9.1 (I/O1)
unnamed: J3.5, U8.3 (I/O2)
unnamed: J3.6, U8.1 (I/O1)
unnamed 67: J10.1, Q2.3 (E); also elsewhere on the board
unnamed: J16.1, U5.39 (PE8)
unnamed: J17.1, U5.40 (PE9)
unnamed: J18.1, U5.41 (PE10)
unnamed: J19.1, U5.85 (PD4)
unnamed: J20.1, U5.82 (PD1)
unnamed: J21.1, U5.81 (PD0)
unnamed: J22.1, U5.84 (PD3)
unnamed: J23.1, U5.42 (PE11)
unnamed: J24.1, U5.51 (PB12)
unnamed: L1.1, U3.3 (SW)
unnamed: Q2.1 (B), R19.2
unnamed: R1.1, R6.2, U1.1 (STAT)
unnamed: R5.2, U1.5 (PROG)
RESET: C13.2, J12.5, SW8.2 (B), U5.14 (NRST); also elsewhere on the board
SD_CK: J6.5 (CLX), U5.80 (SDIO_CK/PC12)
SD_CMD: J6.3 (CMD), R21.2, U5.83 (SDIO_CMD/PD2)
SD_D0: J6.7 (DAT0), R22.2, U5.65 (SDIO_D0/PC8)
SD_D1: J6.8 (DAT1), R23.2, U5.66 (SDIO_D1/PC9)
SD_D2: J6.1 (DAT2), R7.2, U5.78 (SDIO_D2/PC10)
SD_D3: J6.2 (CD/DAT3), R20.2, U5.79 (SDIO_D3/PC11)
SD_DETECT: J6.9 (DET), U5.77 (PA15)
SWO_RX: J13.1, U5.26 (PA3)
SWO_SWO: J12.6, U5.89 (PB3); also elsewhere on the board
SWO_TCK: J12.2, U5.76 (PA14); also elsewhere on the board
SWO_TMS: J12.4, U5.72 (PA13); also elsewhere on the board
SWO_TX: J13.3, U5.25 (PA2)
SYS_LED: D4.2 (A), U5.37 (PB2)
TS_ADC1: J5.16, U5.31 (PA6)
TS_ADC2: J5.17, U5.32 (PA7)
TS_P1: J5.18, U5.96 (PB9)
TS_P2: J5.19, U5.95 (PB8)
USART2_RX: U2.1 (TXD), U5.87 (PD6)
USART2_TX: U2.4 (RXD), U5.86 (PD5)
USART3_RX: U5.48 (PB11), U8.6 (I/O1)
USART3_TX: U5.47 (PB10), U8.4 (I/O2)
USB_D+: R4.2, U6.4 (I/O2)
USB_D-: R3.2, U6.6 (I/O1)
USB_VBUS: D1.2 (A), D2.2 (A), J2.1 (VBUS), Q1.1 (G), R13.1, U1.4 (VDD), U6.5 (VBUS)
VBATT_SENSE: R12.2, R14.1, U5.35 (PB0)
VBUS_SENSE: R13.2, R15.1, U5.38 (PE7)

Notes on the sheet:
ST-Link Programming connector and debug serial
Board Revision detection Rev1: Both pins are floating Rev2: BoardRevDetect1 is connected to 3.3V BoardRevDetect2 is floating
Buzzer is on the PA4 by default.
LCD Backlight power switch
SD card slot
Internal expansion connector
LCD board connector
Bottom Expansion and its ESD protection
Batt to 3.3V reg NCP1529 will cut of at 2.4V
Charging circuit
USB Connector
Optional FTDI
Buttons
Voltage reference on pin PB1
ST-Link connection: 1 - 3.3V 2 - SWCLK 3 - GND 4 - SWDIO 5 - RST 6 - Not connected

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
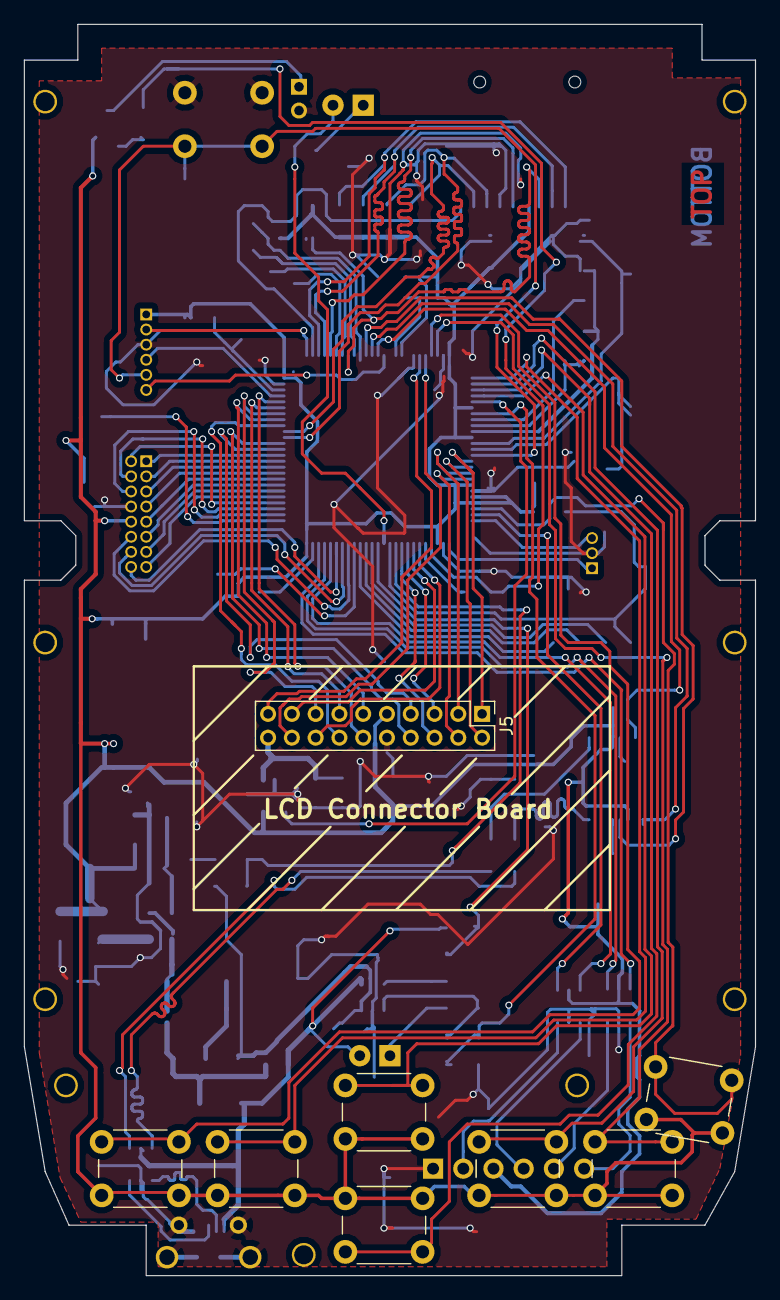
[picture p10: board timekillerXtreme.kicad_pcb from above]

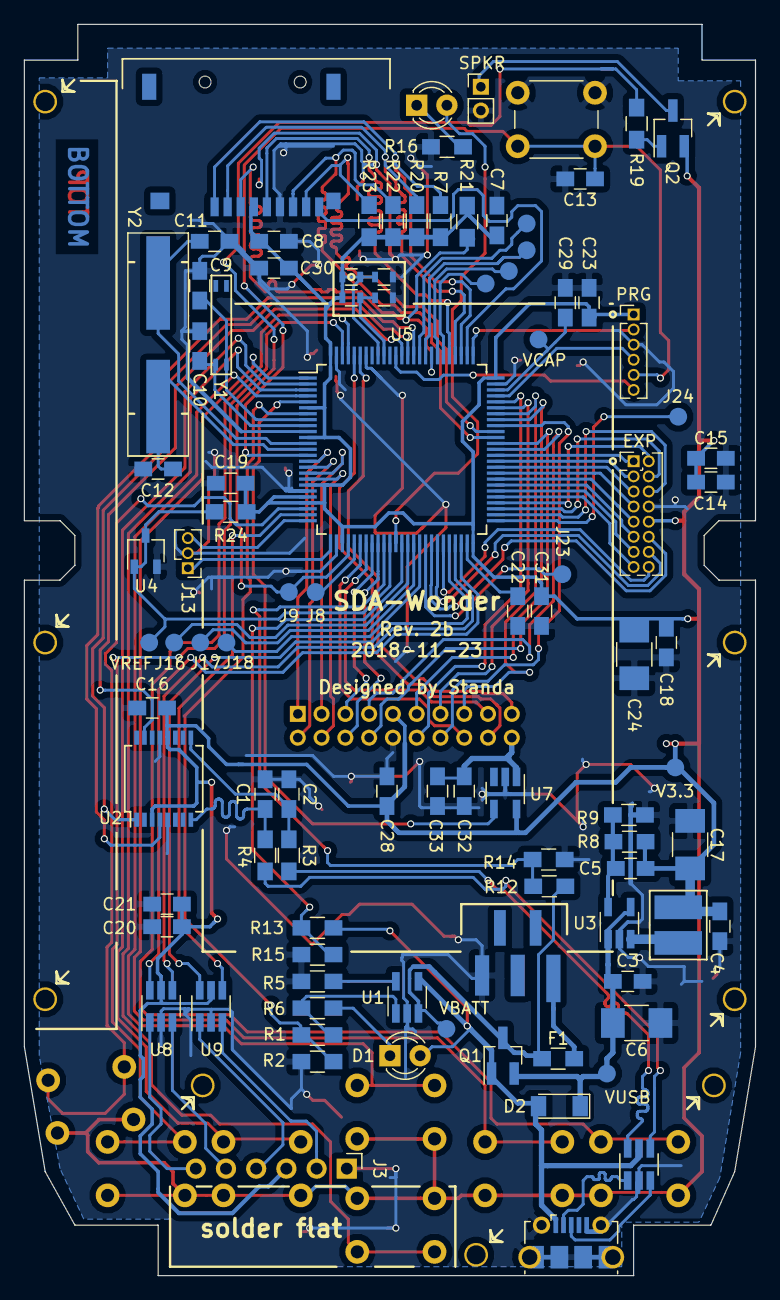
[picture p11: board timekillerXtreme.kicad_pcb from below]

Board: 2 copper layers, 61.5 x 105.2 mm, 105 parts (97 on the bottom side), 108 nets.

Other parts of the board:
EXP: Conn_Internal_Expansion; Pin_Header_Straight_2x08_Pitch1.27mm
PRG: PROG; Pin_Header_Straight_1x06_Pitch1.27mm
SPKR: Conn_01x02; Pin_Header_Straight_1x02_Pitch2.00mm
V3.3: TP_3.3V; Measurement_Point_Round-SMD-Pad_Small
VBATT: TP_BATT; Measurement_Point_Round-SMD-Pad_Small
VCAP: VCAP; Measurement_Point_Round-SMD-Pad_Small
VREF: VREF; Measurement_Point_Round-SMD-Pad_Small
VUSB: TP_USB; Measurement_Point_Round-SMD-Pad_Small

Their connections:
BATT+: VBATT.1; also elsewhere on the board
EXC2_01: EXP.1; also elsewhere on the board
EXC2_02: EXP.3; also elsewhere on the board
EXC2_03: EXP.5; also elsewhere on the board
EXC2_04: EXP.7; also elsewhere on the board
EXC2_05: EXP.9; also elsewhere on the board
EXC2_06: EXP.11; also elsewhere on the board
EXC2_07: EXP.13; also elsewhere on the board
EXC2_08: EXP.15; also elsewhere on the board
EXC2_09: EXP.2; also elsewhere on the board
EXC2_10: EXP.4; also elsewhere on the board
EXC2_11: EXP.6; also elsewhere on the board
EXC2_14: EXP.12; also elsewhere on the board
EXC2_15: EXP.14; also elsewhere on the board
EXC2_16: EXP.16; also elsewhere on the board
GND: EXP.8, PRG.3, SPKR.2; also elsewhere on the board
unnamed 48: VUSB.1; also elsewhere on the board
unnamed 55: VCAP.1; also elsewhere on the board
unnamed 67: SPKR.1; also elsewhere on the board
RESET: PRG.5; also elsewhere on the board
SWO_SWO: PRG.6; also elsewhere on the board
SWO_TCK: PRG.2; also elsewhere on the board
SWO_TMS: PRG.4; also elsewhere on the board

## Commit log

2018-08-31 Initial commit.
    [timekillerXtreme.kicad_pcb, timekillerXtreme.sch, wonder.fcstd]
2018-09-03 LCD connector board added.
    [LCD-Conn.kicad_pcb, LCD-Conn.sch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]
2018-09-03 Board: SD slot moved, usb-conn changed from slots to holes. LCD board polished. Repo cleaned up.
    [LCD-Conn.kicad_pcb, timekillerXtreme.kicad_pcb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]
2018-09-03 pcbs polished a bit. Case bottom pcb clearance enlarged.
    [LCD-Conn.kicad_pcb, timekillerXtreme.kicad_pcb, wonder.fcstd]
2018-09-03 Daily commit 3.9.2018: sd moved to the right position (hopefully). minor case tweaks.
    [timekillerXtreme.kicad_pcb, wonder.fcstd]
2018-09-04 SD card slot moved a bit again.
    [timekillerXtreme.kicad_pcb]
2018-09-06 system board polished, lcd flex connector footprint updated.
    [LCD-Conn.kicad_pcb, LCD-Conn.sch, _saved_LCD-Conn.sch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]
2018-09-06 Silkscreen fixed. Some minor tweaks.
    [timekillerXtreme.kicad_pcb, timekillerXtreme.sch]
2018-10-14 First round of modifications for rev.1
    [LCD-Conn.kicad_pcb, timekillerXtreme.kicad_pcb, timekillerXtreme.sch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]
2018-10-22 Keeping repo up to date.
    [timekillerXtreme.kicad_pcb, timekillerXtreme.sch]
2018-10-30 Rev. 1 updates.
    [timekillerXtreme.kicad_pcb]
2018-10-30 Readme added.
    [timekillerXtreme.kicad_pcb]
2018-11-07 board & schematics updated
    [timekillerXtreme.kicad_pcb, timekillerXtreme.sch]
2018-11-14 Case and board updated, this will be shipped to the boardhouse and I will call it rev2 if it is ok.
    [timekillerXtreme.kicad_pcb, timekillerXtreme.sch]
2018-11-16 Vref fixed, board was sent to boardhouse.
    [timekillerXtreme.kicad_pcb, timekillerXtreme.sch]
2018-11-19 Schematics date and revision synced wit board. Misc case updates.
    [timekillerXtreme.sch]
2018-11-23 PCB fixes after Rev2 assembly, new assembly docs added.
    [timekillerXtreme.kicad_pcb, timekillerXtreme.sch, timekillerXtreme_bom_0.csv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]
2019-01-21 Back adjusted so they doesn't interfere with sd card slot.
2023-05-09 added second revision of the case
2023-07-03 Second revision of the case finalized
